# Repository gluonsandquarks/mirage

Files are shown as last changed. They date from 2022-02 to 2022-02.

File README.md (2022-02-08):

# Mirage

Custom PCB board inspired by the [#badgelife](https://www.youtube.com/watch?v=G2fHKRONc6U) and PCB Art movement. The "Mirage" badge represents to me a kind of miracle because it demonstrates that without prior knowledge, thanks to all the available free information out there, it is possible to build systems from scratch and, on top of that, style them and express ourselves.

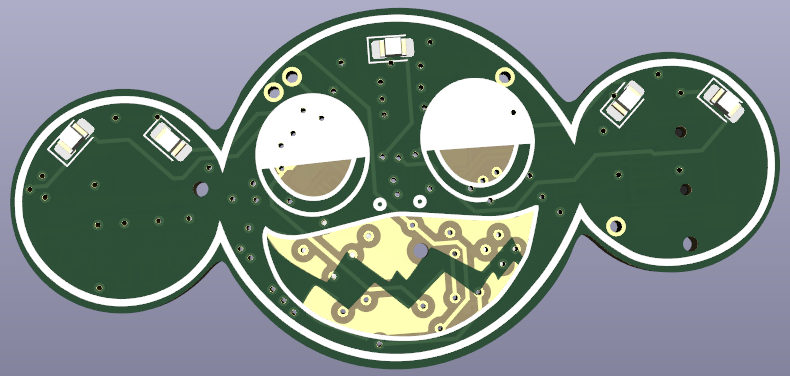
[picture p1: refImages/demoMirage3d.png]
3D View

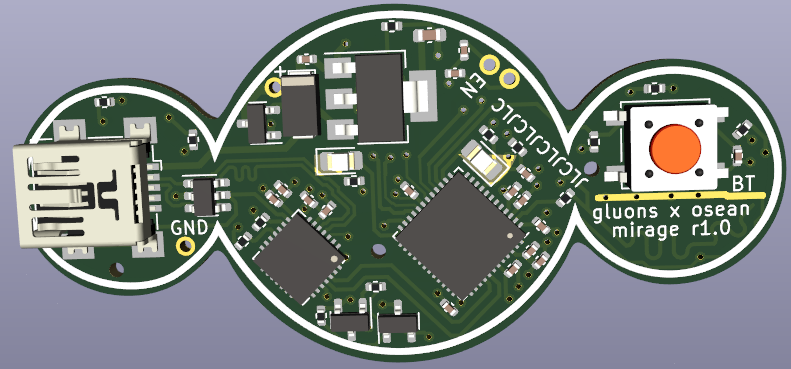
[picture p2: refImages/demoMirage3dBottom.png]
3D View Bottom


The art of the board itself is NOT done by me, it's all done by the wonderful [@OseanWorld](https://twitter.com/oseanworld). Huge props to Osean for keeping me and everyone in the community dreaming and doing art, and thanks for creating such a beautiful cyberspace.

## Hardware

The modules and components used in this board are the following:
- ESP32-PICO-D4: MCU + BLE transciever.
- CP2102-GMR: USB-to-UART converter. Needed to upload code and debug via UART.
- S8050 NPN transistors: needed to detect automatically when code is being uploaded to the MCU. 
- AMS1117-3.3: 5V to 3.3V regulator.
- AO3401A P channel MOSFET: works as reverse polarity protection.
- USBLC6-2SC6: diode array for ESD protection.
- M7 Diode.
- USB Mini B connector.
- 1 push buttons.
- Shitload of capacitors, resistors, LEDs.

All the references and datasheets of the components used in the schematic can be found in the `/datasheets` directory.

If you want to learn the technicalities of designing a PCB yourself you can checkout [Phil's Lab youtube channel](https://www.youtube.com/c/PhilS94) for an intro to PCB design.

### RF Section
The design includes an RF portion which is *"designed"* for BLE communications. With "designed" being in quotes because this is my first RF design and my first time making a PCB trace antenna. The hard truth about RF is that there's no real way of tuning the antenna or making a matching Pi Network without some sort of expensive equipment (although the NanoVNAs are pretty cheap nowadays). I don't have access to these tools so I just winged it by calculating a 50 Ohm impedance microstrip line and using a 0 Ohm resistor as a jumper wire. The antenna trace is between 20 mm - 25 mm in length (given the 2.45 GHz frequency of BLE) but it's a mess right now and I don't know if it will work at all. I'll update this section once the PCBs arrive and I've written some firmware to make two boards talk to each other. 

## Firmware

## Art
The art of this board was made entirely inside Inkscape and ported to KiCad thanks to the [svg2shenzhen](https://github.com/badgeek/svg2shenzhen) extension made by [@badgeek](https://github.com/badgeek). Also the great [video tutorial](https://www.youtube.com/watch?v=Sbkvza8cKQE) done by [@mrtwinkletwink](https://twitter.com/mrtwinkletwink) helped me a lot when it came to understand the different layers of the board and how to use svg2shenzhen in general.

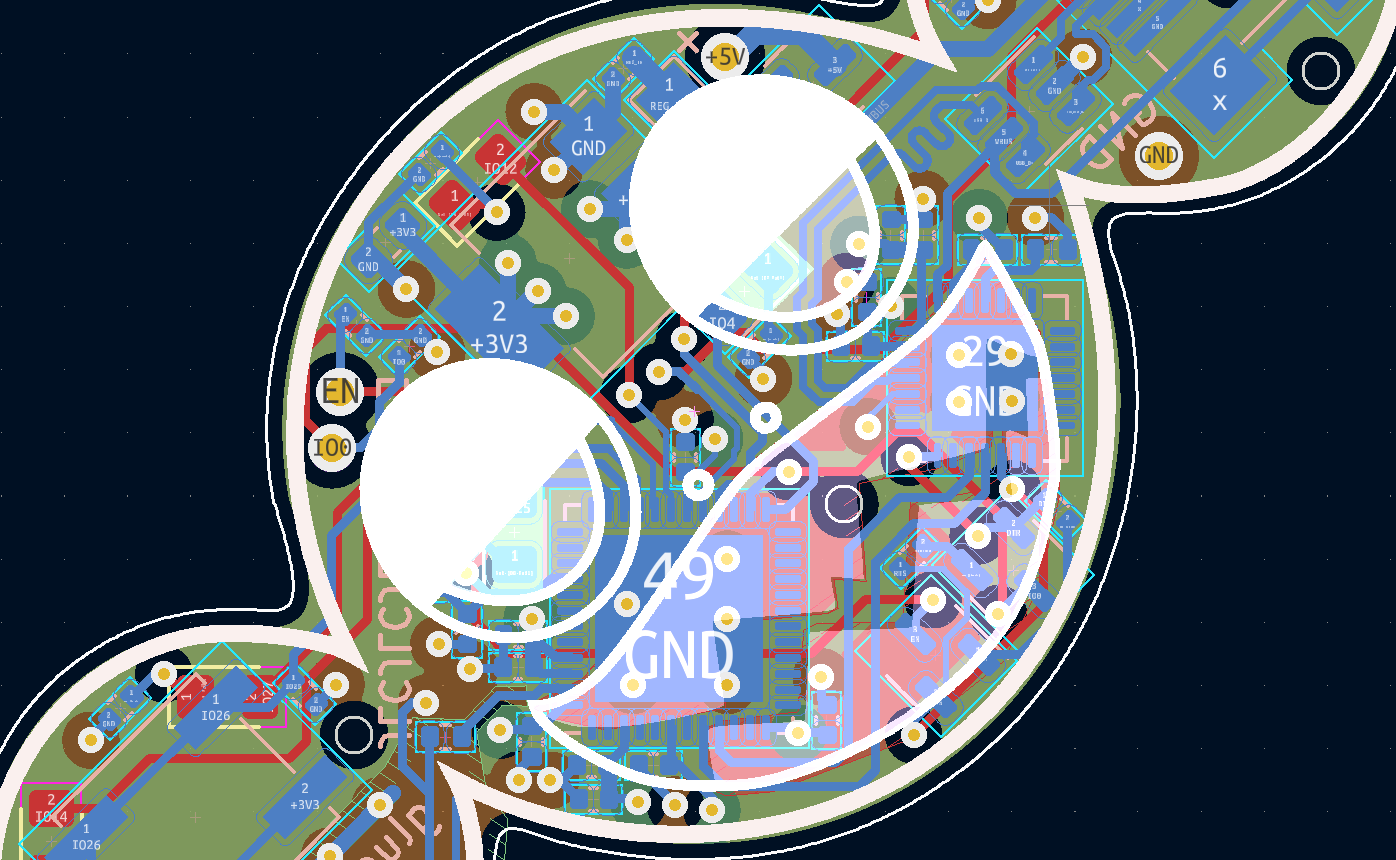
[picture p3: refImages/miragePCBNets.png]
PCB View


## Directory Structure
As you can see, right now the repo is pretty unorganized. Maybe I'll restructure it in the future, but as of now here are the main files:

- **\*.kicad**: This files contain all the relevant design for the electrical part of the board. The *.kicad_pro* file is the main file you'll want to open (by double clicking on it). The *.kicad_sch* contains the schematic for the board. The *kicad_pcb* contains the layout for the components and the overall PCB design.
- **nudeko.pretty**: contains the custom PCB outline, silkscreen and copper layers which done in Inkscape. *You'll have to load this module into your footprint library if KiCad doesn't do that automatically.*
- **nudeko.svg**: This file contains the vector art. It was done in Inkscape and the document was prepared and imported to KiCad with the [svg2shenzhen](https://github.com/badgeek/svg2shenzhen) extension made by [@badgeek](https://github.com/badgeek).
- **symbols**: This directory contains a custom library I made for KiCad. It only contains the M7 diode footprint. If KiCad doesn't recognize this automatically you'll have to tell it where it's located.
- **nudekoINK2KICAD**: Contains the files generated by the svg2shenzhen extension. Might delete this in the future cause it only adds junk to the repo.
- **datasheets**: As its name implies, here are the datasheets of each component I used for the electronics (aside from passive components). You could use other components if you know what you're doing but this is what was in stock (or was a basic part for the most part) at [JLCPCB](https://jlcpcb.com/).
- **MirageR1-backups**: Generated automatically by KiCad. Might delete this guys too.

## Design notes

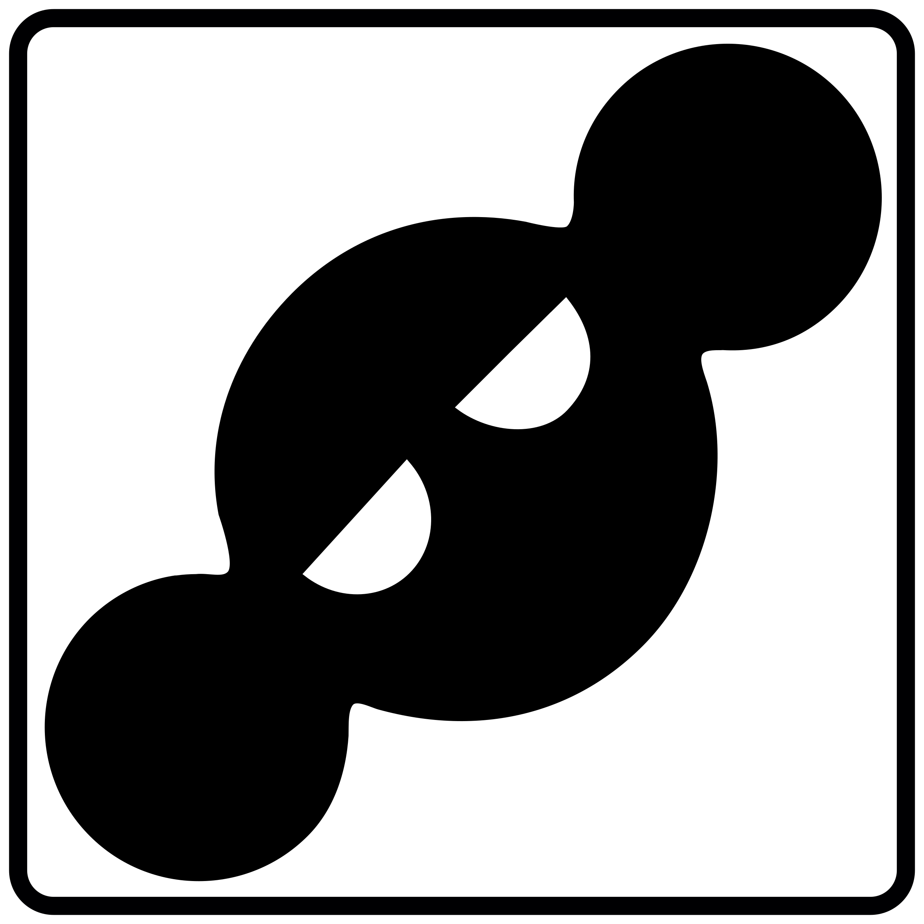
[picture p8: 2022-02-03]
nuDekoINK2KICAD/.svg2shenzhen-cache/images/B.Cu_g21.png

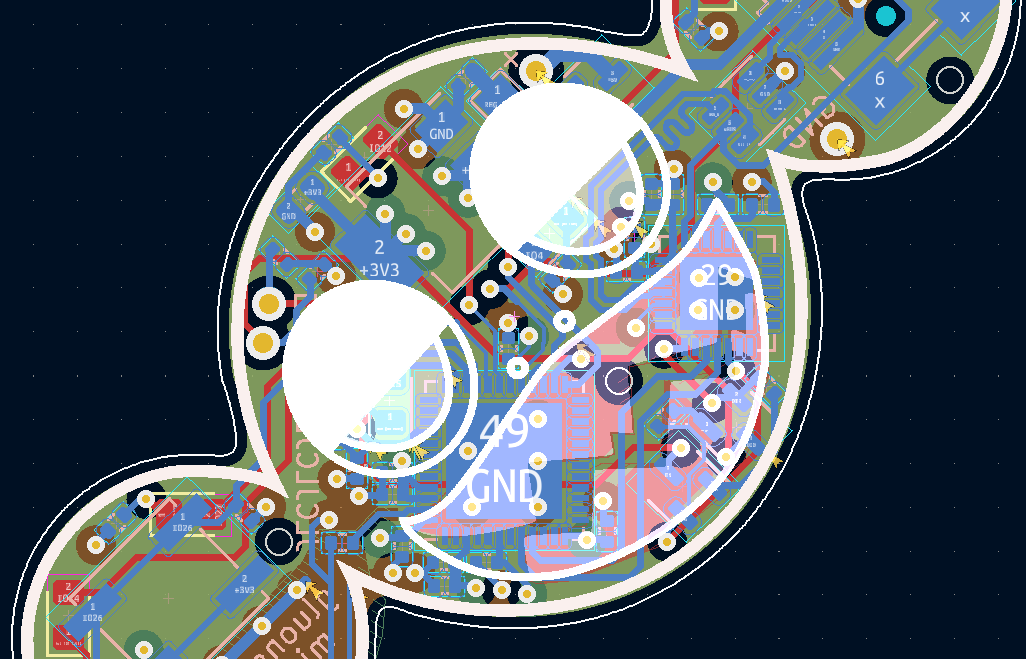
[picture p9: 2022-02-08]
refImages/mirageDemo.png

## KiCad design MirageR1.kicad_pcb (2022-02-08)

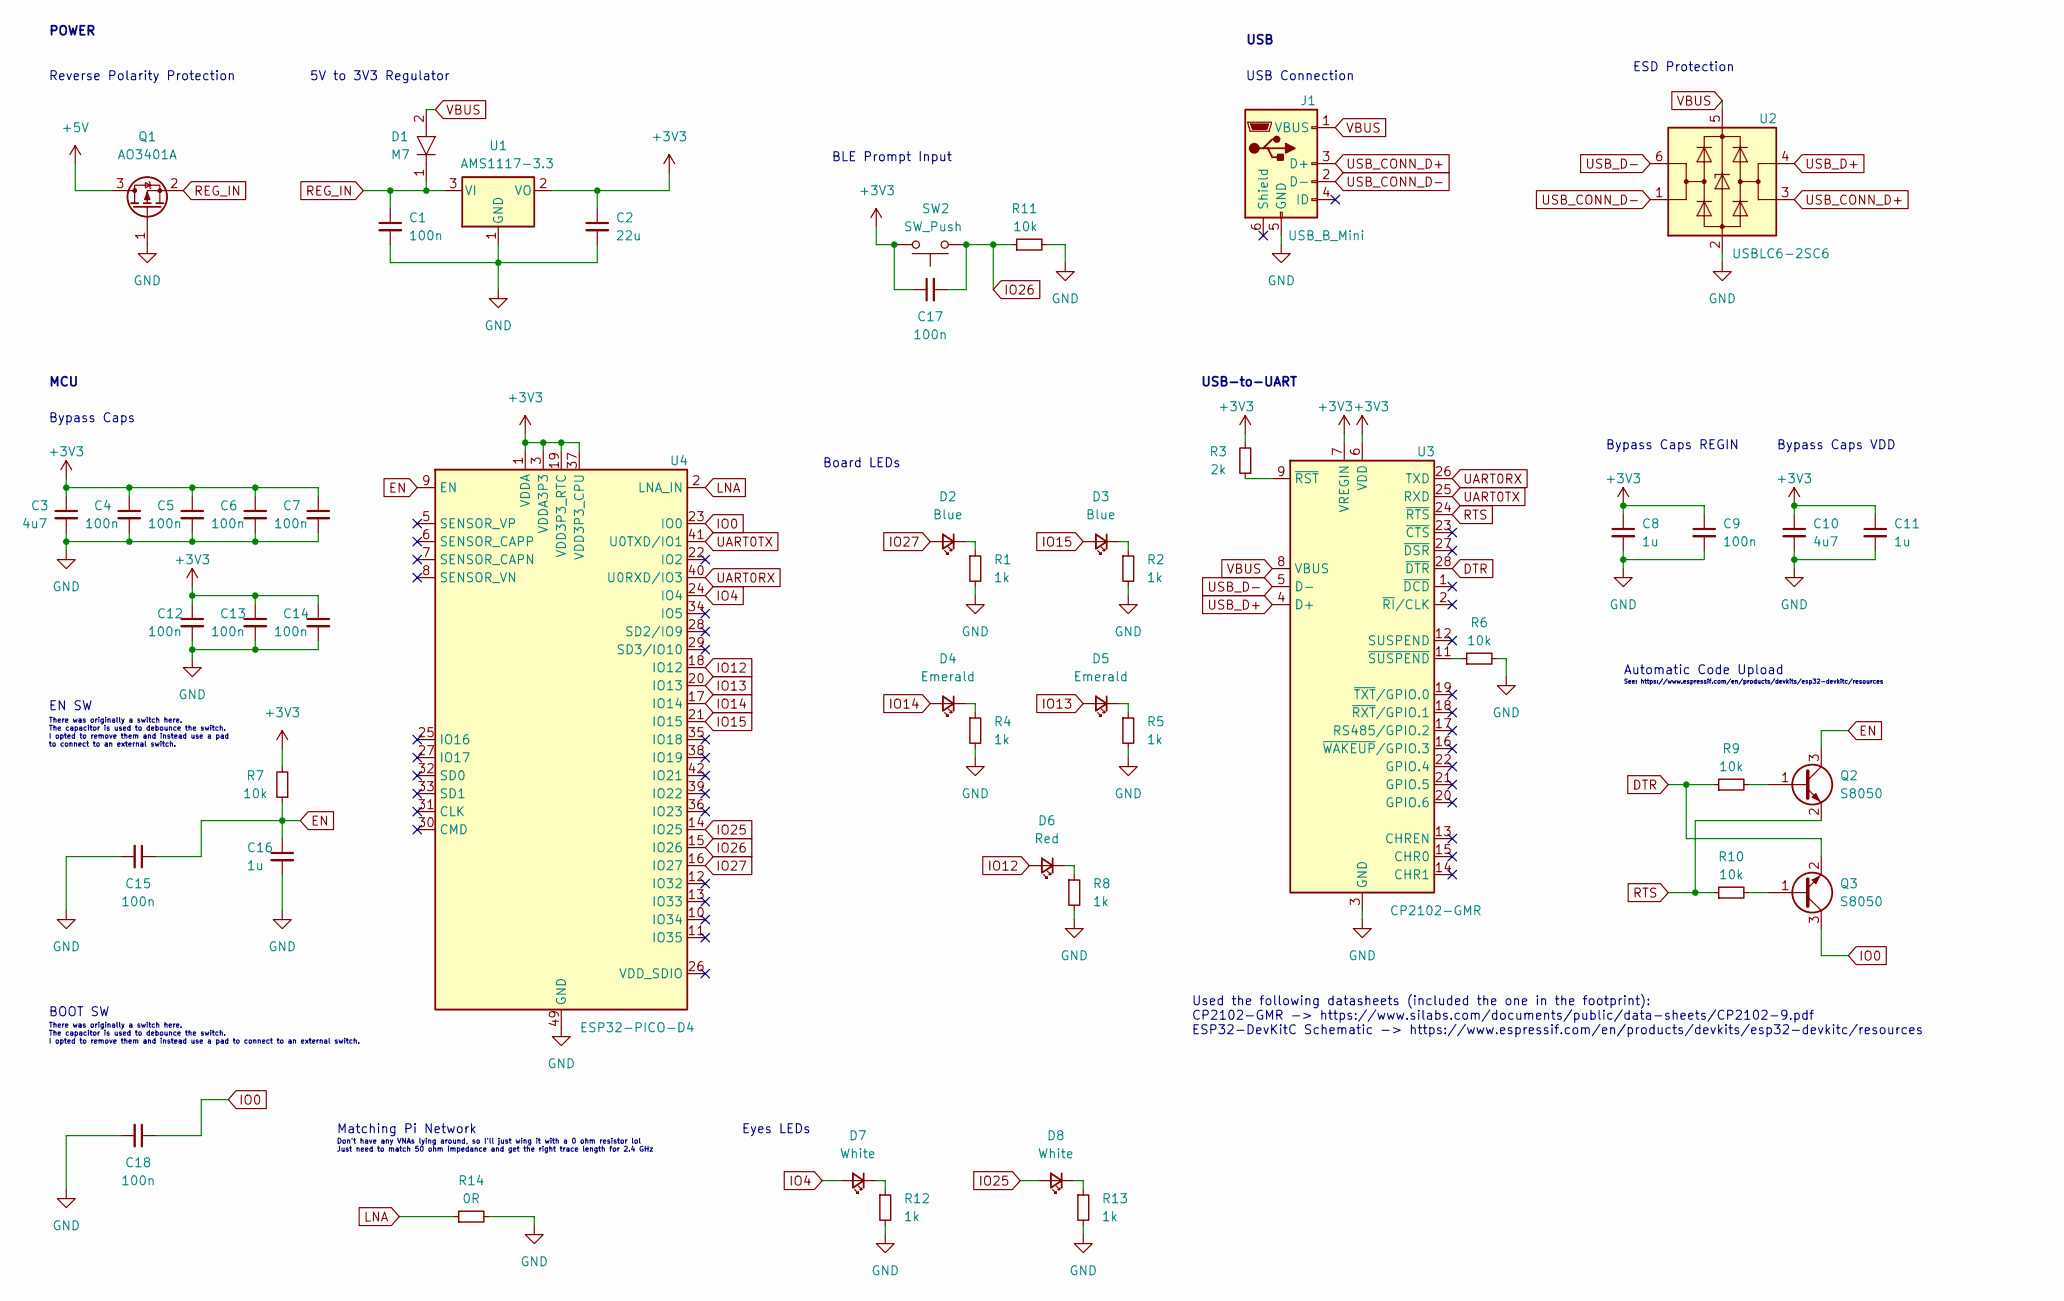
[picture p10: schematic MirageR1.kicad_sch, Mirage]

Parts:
C1, C4, C5, C6, C7, C9, C12, C13, C14, C15, C17, C18: 100n; C_0402_1005Metric
C2: 22u; C_0603_1608Metric
C3, C10: 4u7; C_0402_1005Metric
C8, C11, C16: 1u; C_0402_1005Metric
D1: M7; D_MiniMELF
D2, D3: Blue; LED_0805_2012Metric_Pad1.15x1.40mm_HandSolder
D4, D5: Emerald; LED_0805_2012Metric_Pad1.15x1.40mm_HandSolder
D6: Red; LED_0805_2012Metric_Pad1.15x1.40mm_HandSolder
D7, D8: White; LED_0805_2012Metric_Pad1.15x1.40mm_HandSolder
J1: USB_B_Mini; USB_Mini-B_Wuerth_65100516121_Horizontal
Q1: AO3401A; SOT-23
Q2, Q3: S8050; SOT-23
R1, R2, R4, R5, R8, R12, R13: 1k; R_0402_1005Metric
R3: 2k; R_0402_1005Metric
R6, R7, R9, R10, R11: 10k; R_0402_1005Metric
R14: 0R; R_0402_1005Metric
SW2: SW_Push; SW_Push_1P1T_NO_CK_KSC6xxJ
U1: AMS1117-3.3; SOT-223-3_TabPin2
U2: USBLC6-2SC6; SOT-23-6
U3: CP2102-GMR; QFN-28-1EP_5x5mm_P0.5mm_EP3.35x3.35mm
U4: ESP32-PICO-D4; QFN-48-1EP_7x7mm_P0.5mm_EP5.3x5.3mm

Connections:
+3V3: C2.1, C3.1, C4.1, C5.1, C6.1, C7.1, C8.1, C9.1, C10.1, C11.1, C12.1, C13.1, C14.1, C17.1, R3.2, R7.2, SW2.2, U1.2 (VO), U3.6 (VDD), U3.7 (VREGIN), U4.1 (VDDA), U4.3 (VDDA3P3), U4.4 (VDDA3P3), U4.19 (VDD3P3_RTC), U4.37 (VDD3P3_CPU), U4.43 (VDDA), U4.46 (VDDA)
+5V: Q1.3 (D)
DTR: Q3.2 (E), R9.1, U3.28 (~DTR)
EN: C15.1, C16.1, Q2.3 (C), R7.1, U4.9 (EN)
GND: C1.2, C2.2, C3.2, C4.2, C5.2, C6.2, C7.2, C8.2, C9.2, C10.2, C11.2, C12.2, C13.2, C14.2, C15.2, C16.2, C18.2, J1.5 (GND), Q1.1 (G), R1.2, R2.2, R4.2, R5.2, R6.2, R8.2, R11.2, R12.2, R13.2, R14.2, U1.1 (GND), U2.2 (GND), U3.3 (GND), U3.29 (GND), U4.49 (GND)
IO0: C18.1, Q3.3 (C), U4.23 (IO0)
IO4: D7.2 (A), U4.24 (IO4)
IO12: D6.2 (A), U4.18 (IO12)
IO13: D5.2 (A), U4.20 (IO13)
IO14: D4.2 (A), U4.17 (IO14)
IO15: D3.2 (A), U4.21 (IO15)
IO25: D8.2 (A), U4.14 (IO25)
IO26: C17.2, R11.1, SW2.1, U4.15 (IO26)
IO27: D2.2 (A), U4.16 (IO27)
LNA: R14.1, U4.2 (LNA_IN)
unnamed: D2.1 (K), R1.1
unnamed: D3.1 (K), R2.1
unnamed: D4.1 (K), R4.1
unnamed: D5.1 (K), R5.1
unnamed: D6.1 (K), R8.1
unnamed: D7.1 (K), R12.1
unnamed: D8.1 (K), R13.1
unnamed: Q2.1 (B), R9.2
unnamed: Q3.1 (B), R10.2
unnamed: R3.1, U3.9 (~RST)
unnamed: R6.1, U3.11 (~SUSPEND)
REG_IN: C1.1, D1.1, Q1.2 (S), U1.3 (VI)
RTS: Q2.2 (E), R10.1, U3.24 (~RTS)
UART0RX: U3.26 (TXD), U4.40 (U0RXD/IO3)
UART0TX: U3.25 (RXD), U4.41 (U0TXD/IO1)
USB_CONN_D+: J1.3 (D+), U2.3 (I/O2)
USB_CONN_D-: J1.2 (D-), U2.1 (I/O1)
USB_D+: U2.4 (I/O2), U3.4 (D+)
USB_D-: U2.6 (I/O1), U3.5 (D-)
VBUS: D1.2, J1.1 (VBUS), U2.5 (VBUS), U3.8 (VBUS)

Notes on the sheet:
Automatic Code Upload
Bypass Caps
Bypass Caps VDD
EN SW
Used the following datasheets (included the one in the footprint): CP2102-GMR -> https://www.silabs.com/documents/public/data-sheets/CP2102-9.pdf ESP32-DevKitC Schematic -> https://www.espressif.com/en/products/devkits/esp32-devkitc/resources
BLE Prompt Input
Matching Pi Network
There was originally a switch here. The capacitor is used to debounce the switch. I opted to remove them and instead use a pad to connect to an external switch.
5V to 3V3 Regulator
USB-to-UART
There was originally a switch here. The capacitor is used to debounce the switch. I opted to remove them and instead use a pad to connect to an external switch.
BOOT SW
ESD Protection
Bypass Caps REGIN
Eyes LEDs
See: https://www.espressif.com/en/products/devkits/esp32-devkitc/resources
USB Connection
MCU
Don't have any VNAs lying around, so I'll just wing it with a 0 ohm resistor lol Just need to match 50 ohm impedance and get the right trace length for 2.4 GHz
USB
Board LEDs
POWER
Reverse Polarity Protection

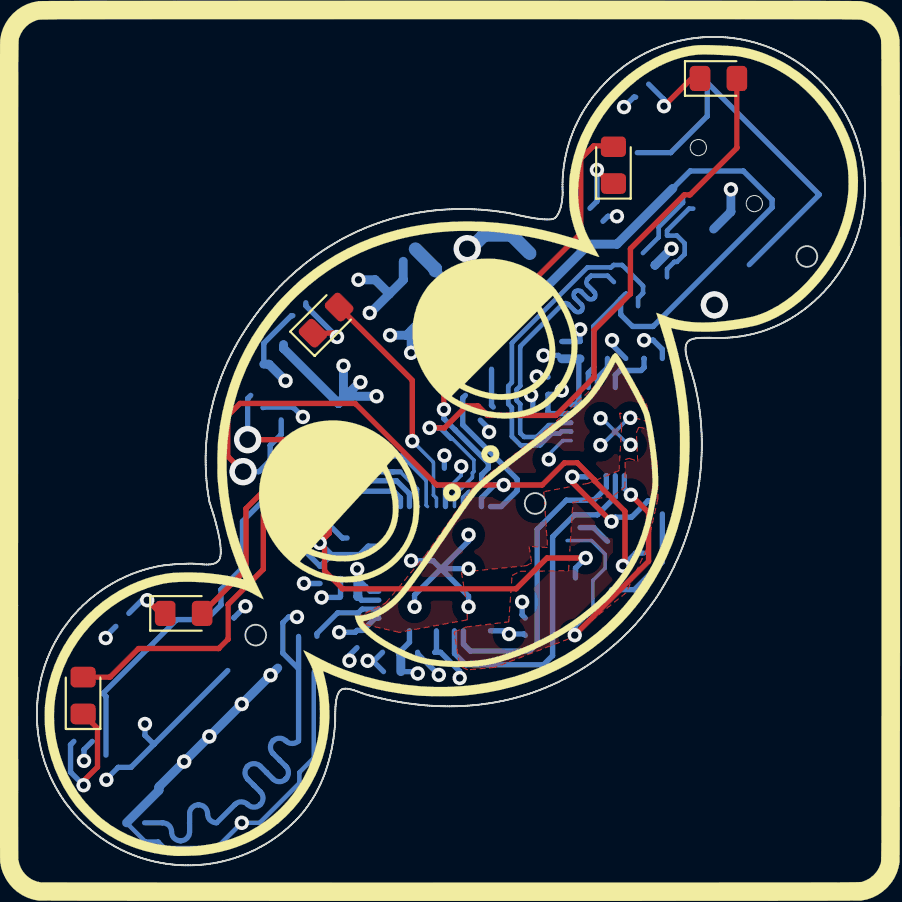
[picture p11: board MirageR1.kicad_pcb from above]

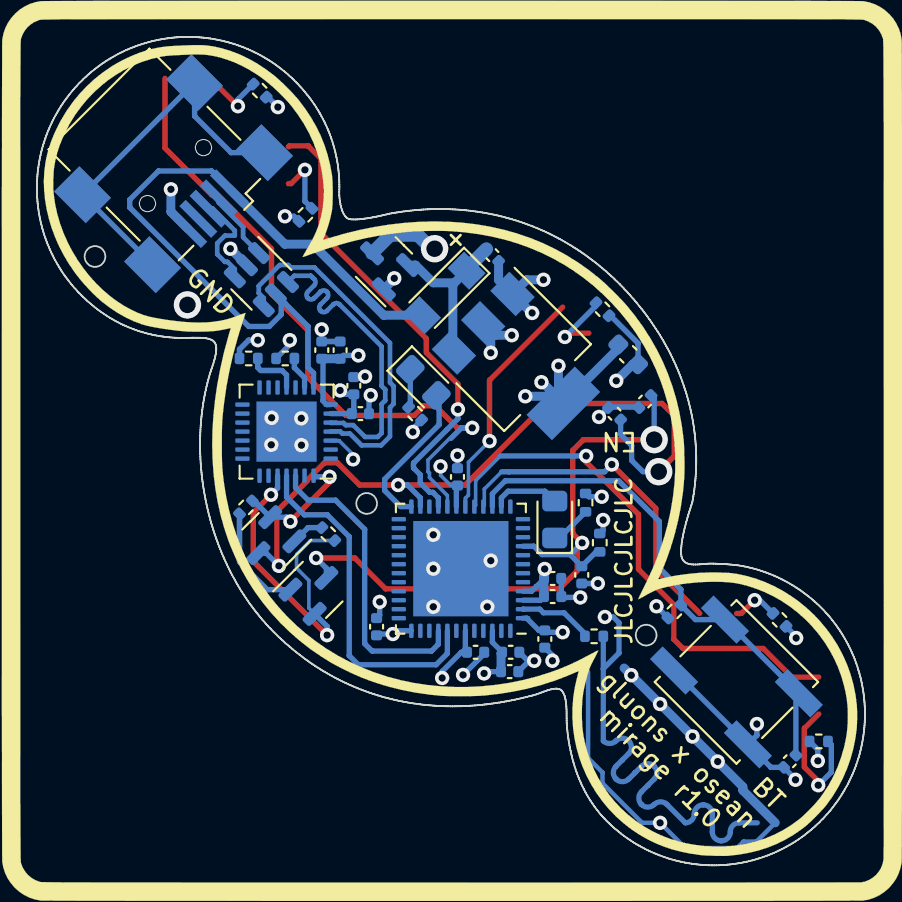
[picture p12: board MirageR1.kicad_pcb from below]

Board: 4 copper layers, 46.0 x 46.0 mm, 50 parts (44 on the bottom side), 34 nets.

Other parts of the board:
Ref**: Val**; nudeko

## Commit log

2022-01-26 added mounting pads i guess
    [MirageR1.kicad_sch]
2022-02-03 designed the pcb board w/ a 50x50 mm constrain
    [MirageR1.kicad_sch]
2022-02-08 finished routing, added gerber files, added footprint positioning file, modified the PCB soldermask, did some bad decisions with my life
    [MirageR1-B_Cu.gbr, MirageR1-B_Mask.gbr, MirageR1-B_Paste.gbr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]
